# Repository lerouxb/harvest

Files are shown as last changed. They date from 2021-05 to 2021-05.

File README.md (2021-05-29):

Harvest
===

A super low power energy-harvesting wifi temperature, humidity and voltage logger plus timelapse camera.

Very much a work in progress.

See https://lerouxb.co/2021/05/13/energy-harvesting-wifi.html for more details.

tl;dr
---

5.5V solar panel charges a 5.5V or 6V multi-farad supercapacitor. An attiny 1614 (could be smaller flash or pin count, could be 0 series as well - this is just what I had on hand) is connected straight to the supercapacitor. It measures its own supply voltage. If that is > 3.6V it powers a esp32 cam through a p-channel mosfet and 350mv dropout linear regulator. The esp32 cam reads a DHT22 to get temperature and humidity and asks the attiny for the supply voltage over i2c. It then connects to wifi and publishes those three values to an MQTT broker. Then it asks the attiny over i2c to cut the power. The attiny sleeps almost all the time. It just wakes up every second from the RTC and also when its i2c address matches. If 10 seconds passes without the esp32 signalling that it is done it will also cut the power as a failsafe just in case it is stuck. Every 60 seconds if the supply voltage is high enough it powers up the esp32 again and the cycle starts over.

Why an esp32 cam? So I can also use it to periodically take pictures and assemble them into a timelapse on the server.

Since the attiny is running at nominally 5V-ish and the esp32 at a regulated 3.3V, there's a [level shifter](https://cdn-shop.adafruit.com/datasheets/an97055.pdf) for the i2c bus.

The server also has an MQTT subscriber that stores the values in a mongo database that we can then pull out and graph.

An obvious optimisation would be to not even bother turning the esp32 on or taking pictures after sunset and before sunrise.

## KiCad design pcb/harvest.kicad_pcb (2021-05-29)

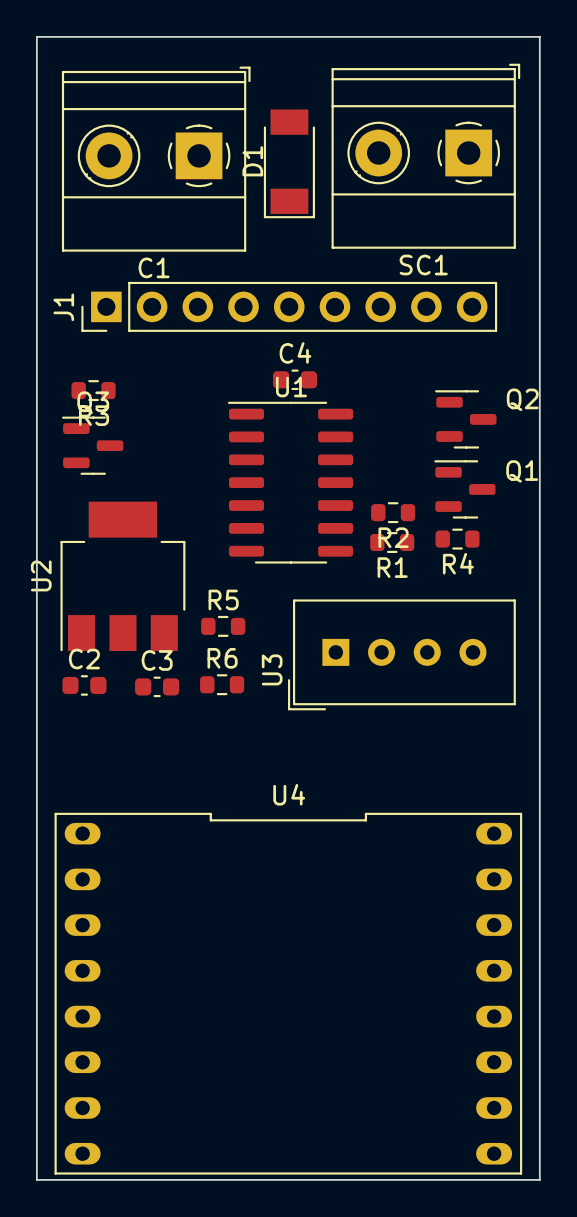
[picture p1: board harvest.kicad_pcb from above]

Board: 2 copper layers, 27.9 x 63.5 mm, 20 parts (0 on the bottom side), 17 nets, no tracks yet.

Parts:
C1: 5.5V / 2.5F; TerminalBlock_Phoenix_MKDS-1,5-2_1x02_P5.00mm_Horizontal
C2: 4.7uF; C_0603_1608Metric
C3: 1uF; C_0603_1608Metric
C4: 100n; C_0603_1608Metric
D1: D_Schottky; D_SOD-128
J1: Conn_01x09; PinHeader_1x09_P2.54mm_Vertical
Q1, Q2: DMN6140L; SOT-23
Q3: DMG2301L; SOT-23
R1, R2, R3, R4, R5, R6: 10k; R_0603_1608Metric
SC1: Solar_Cells; TerminalBlock_Phoenix_MKDS-1,5-2_1x02_P5.00mm_Horizontal
U1: ATtiny1614-SS; SOIC-14_3.9x8.7mm_P1.27mm
U2: MCP1825S; SOT-223-3_TabPin2
U3: DHT11; Aosong_DHT11_5.5x12.0_P2.54mm
U4: esp32-cam

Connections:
+3V3: C3.1, J1.2, Q1.1 (G), Q2.1 (G), R4.1, R5.1, R6.1, U2.3 (VO), U3.1 (VCC), U4.16 (3.3V)
+5V: C1.1, C4.1, D1.1 (K), J1.1, Q3.3 (D), R1.1, R2.1, R3.1, U1.1 (VCC)
ATTINY_RX: J1.6, U1.12 (PA2)
ATTINY_SCL: Q2.3 (D), R2.2, U1.9 (PB0)
ATTINY_SDA: Q1.3 (D), R1.2, U1.8 (PB1)
ATTINY_TX: J1.7, U1.11 (PA1)
ESP32_RX: J1.8, U4.11 (GPIO_3_/_RXD)
ESP32_SCL: Q2.2 (S), R6.2, U4.3 (GPIO_12)
ESP32_SDA: Q1.2 (S), R5.2, U4.4 (GPIO_13)
ESP32_TX: J1.9, U4.10 (GPIO_1_/_TXD)
GND: C1.2, C2.2, C3.2, C4.2, J1.5, SC1.2 (-), U1.14 (GND), U2.2 (GND), U3.4 (GND), U4.2 (GND), U4.9 (GND), U4.13 (GND)
GPIO_0: J1.4, U4.14 (GPIO_0)
unnamed: C2.1, Q3.2 (S), U2.1 (VI)
unnamed: D1.2 (A), SC1.1 (+)
unnamed: Q3.1 (G), R3.2, U1.3 (PA5)
unnamed: R4.2, U3.2 (IO), U4.5 (GPIO_15)
UPDI: J1.3, U1.10 (~RESET~/PA0)

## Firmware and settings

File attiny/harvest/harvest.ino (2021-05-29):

#include <avr/sleep.h>
#include <Wire.h>

#define NONE 0
#define WAITING 1
#define VOLTAGE 2
#define SHUTDOWN 3

volatile uint8_t command = NONE;
volatile uint8_t seconds = 0;
volatile uint8_t timeout = 0;
volatile bool wakeFromRTC = false;

void setup() {
  initADC();
  initRTC();
  set_sleep_mode(SLEEP_MODE_PWR_DOWN); // Set sleep mode to POWER DOWN mode
  sleep_enable(); // Enable sleep mode, but not going to sleep yet
  
  Wire.begin(8);
  Wire.onReceive(receiveHandler);
  Wire.onRequest(requestHandler);
  Serial.begin(115200);
  Serial.println("hello");
  pinMode(PIN_PA5, OUTPUT);
  digitalWrite(PIN_PA5, LOW);
}

void loop() {

  cli();
  
  if (command == SHUTDOWN) {
    command = NONE;
    Serial.println("powering down");
    digitalWrite(PIN_PA5, HIGH); // turn off the power to the ESP32
  }

  if (seconds == 60) {
    seconds = 0;
    
    startReadingVoltage();
    double voltage = finishReadingVoltage();

    if (voltage > 3.6) {
      Serial.println("powering up");
      digitalWrite(PIN_PA5, LOW); // turn on the ESP32 after 60 seconds
    }
    else {
      Serial.print("low voltage: ");
      Serial.println(voltage);
    }
  }

  if (command == NONE && !timeout) {
    sei(); // enable interrupts before we sleep
    
    Serial.flush();
    
    sleep_cpu(); // go to sleep until an i2c message comes in or the PIT interrupt wakes us up

    cli(); // disable again because we're using some volatile vars
    
    if (wakeFromRTC) {
        wakeFromRTC = false; // just clear this. don't try and stay awake longer than what's necessary
    }
    else {
      // assume that if we didn't wake from the RTC it was because of i2c, don't go to sleep until we load in the command and finish processing it.
      timeout = 2;
      // NOTE: we're not waking up fast enough, so the onReceive handler gets no data the first time it is called. Easiest workaround I've found is to i2c.scan() in the client before i2c.writeto() 
    }
  }

  sei(); // probably silly, but enable interrupts at the end of the loop
}


void initADC() {
  VREF.CTRLA = VREF_ADC0REFSEL_1V1_gc;
  ADC0.CTRLC = ADC_REFSEL_VDDREF_gc | ADC_PRESC_DIV256_gc; // 78kHz clock
  ADC0.MUXPOS = ADC_MUXPOS_INTREF_gc;                  // Measure INTREF
  ADC0.CTRLA = ADC_ENABLE_bm;                          // Single, 10-bit
}

/*
double measureVoltage() {
  ADC0.COMMAND = ADC_STCONV_bm;                        // Start conversion
  while (ADC0.COMMAND & ADC_STCONV_bm);                // Wait for completion
  uint16_t reading = ADC0.RES;                         // ADC conversion result
  //uint16_t voltage = 11264/reading;
  //Buffer[0] = voltage/10; Buffer[1]= voltage%10;
  return 1126.4 / reading;
}
*/

void startReadingVoltage() {
  ADC0.COMMAND = ADC_STCONV_bm;                        // Start conversion
}

double finishReadingVoltage() {
  while (ADC0.COMMAND & ADC_STCONV_bm);                // Wait for completion
  uint16_t reading = ADC0.RES;                         // ADC conversion result
  return 1126.4 / reading;
 }

void initRTC() {
  // Initialize RTC
  while (RTC.STATUS > 0) {
    ;                                   // Wait for all register to be synchronized
  }
  
  RTC.CLKSEL = RTC_CLKSEL_INT32K_gc;    // 32.768kHz Internal Ultra-Low-Power Oscillator (OSCULP32K)

  RTC.PITINTCTRL = RTC_PI_bm;           // PIT Interrupt: enabled

  RTC.PITCTRLA = RTC_PERIOD_CYC32768_gc // RTC Clock Cycles 16384, resulting in 32.768kHz/32768 = 1Hz
  | RTC_PITEN_bm;                       // Enable PIT counter: enabled
}

ISR(RTC_PIT_vect) {
  RTC.PITINTFLAGS = RTC_PI_bm;          // Clear interrupt flag by writing '1' (required)

  wakeFromRTC = true;
  
  ++seconds;
  if (timeout) {
    --timeout;
  }

  //Serial.print(command);
  //Serial.print(' ');
  //Serial.println(seconds);
}

void receiveHandler(int howMany) {
  //Serial.print("available: ");
  //Serial.print(Wire.available());
  //Serial.print(" howMany:");
  //Serial.println(howMany);
  
  while (Wire.available()) {
    char c = Wire.read();
    Serial.println(c);

    if (c == 'v') { // voltage?
      command = VOLTAGE; // only served noce the client reads
      startReadingVoltage(); // we'll wait for it in requestHandler
    }

    if (c == 's') { // shutdown
      command = SHUTDOWN; // served in the main loop
    }
  }
}

void requestHandler() {
  switch (command) {
      case VOLTAGE: {
        command = NONE;
        char buf[5];
        double voltage = finishReadingVoltage();
        Serial.println(voltage);
        dtostrf(voltage, 5, 3, buf);
        Wire.write(buf, 5);
        break;
      }

      default: {
        break;
      }
  }
}
